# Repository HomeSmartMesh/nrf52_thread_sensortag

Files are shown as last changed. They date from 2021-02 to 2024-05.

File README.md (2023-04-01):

# nrf52_thread_sensortag
nRF52840 small sensor Tag, Low power design, battery operated

# documentation website
https://www.homesmartmesh.com/docs/microcontrollers/nrf52/thread_sensortag/
# community discussion
Free support, feedback and discussions right here on gihub
https://github.com/orgs/HomeSmartMesh/discussions

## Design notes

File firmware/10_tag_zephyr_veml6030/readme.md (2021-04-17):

# sensor tag hello

## environment variables
* `GNUARMEMB_TOOLCHAIN_PATH` = D:\tools\gnu_arm_embedded\9_2020-q2-update
* `ZEPHYR_BASE` = D:\Projects\zephyrproject\zephyr
* `ZEPHYR_TOOLCHAIN_VARIANT` = gnuarmemb

## usage
```bash
west build -b nrf52840_sensortag -- -DCONF_FILE=prj-shell.conf
west build -b nrf52840_sensortag -- -DCONF_FILE=prj-log.conf
west flash
```

error
```log
[00:00:00.325,012] <inf> main: Hello from Sensor Tag I2C example
[00:00:00.325,012] <inf> main: VEML6030 light sensor application

[00:00:00.325,042] <err> main: sensor: device not found.
```

https://docs.zephyrproject.org/latest/guides/porting/board_porting.html

https://stackoverflow.com/questions/62358554/zephyros-how-to-add-driver-module-to-out-of-tree-project

https://www.zephyrproject.org/how-to-build-drivers-for-zephyr-rtos/

https://interrupt.memfault.com/blog/building-drivers-on-zephyr

https://docs.zephyrproject.org/latest/reference/drivers/index.html
https://docs.zephyrproject.org/1.9.0/devices/drivers/drivers.html
https://docs.zephyrproject.org/latest/reference/peripherals/sensor.html

https://www.mouser.com/datasheet/2/427/veml6030-1767367.pdf
https://www.mouser.com/datasheet/2/418/5/NG_DS_MS8607-02BA01_B3-1134999.pdf

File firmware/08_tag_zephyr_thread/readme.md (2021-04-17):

# tag zephyr thread
## usage
```bash
west build -b nrf52840_sensortag -- -DCONF_FILE=prj-shell.conf
west build -b nrf52840_sensortag -- -DCONF_FILE=prj-log.conf
west flash
```
## sample documentation
https://www.homesmartmesh.com/docs/microcontrollers/nrf52/thread_sensortag/#08-tag-zephyr-thread

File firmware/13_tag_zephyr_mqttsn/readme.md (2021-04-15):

# option 1 nRF SDK
* nRF5_SDK_for_Thread_and_Zigbee_v4.1.0_32ce5f8\components\thread\mqtt_sn\mqtt_sn_client
* components\thread\mqtt_sn\mqtt_sn_client

# option 2 kyberpunk
* reference example
https://github.com/kyberpunk/openthread-mqttsn/blob/master/examples/c_mqttsn_publish_without_connect/main.c

* using a forked openthread with mqtt-sn support
https://github.com/kyberpunk/openthread

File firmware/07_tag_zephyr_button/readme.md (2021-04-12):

# sensor tag hello

## environment variables
* `GNUARMEMB_TOOLCHAIN_PATH` = D:\tools\gnu_arm_embedded\9_2020-q2-update
* `ZEPHYR_BASE` = D:\Projects\zephyrproject\zephyr
* `ZEPHYR_TOOLCHAIN_VARIANT` = gnuarmemb

## usage
```bash
west build -b nrf52840_sensortag
west flash
```

config
```bash
-- west build: generating a build system
Including boilerplate (Zephyr base): D:/Projects/zephyrproject/zephyr/cmake/app/boilerplate.cmake
-- Application: D:/Dev/nrf52/nrf52_thread_sensortag/firmware/07_tag_zephyr_button
-- Zephyr version: 2.5.99 (D:/Projects/zephyrproject/zephyr)
-- Found Python3: C:/Users/User/AppData/Local/Programs/Python/Python39/python.exe (found suitable exact version "3.9.0") found components: Interpreter
-- Found west (found suitable version "0.9.0", minimum required is "0.7.1")
-- Board: nrf52840_sensortag
-- Cache files will be written to: D:/Projects/zephyrproject/zephyr/.cache
-- Found toolchain: gnuarmemb (D:/tools/gnu_arm_embedded/9_2020-q2-update)
-- Found BOARD.dts: D:/Dev/nrf52/nrf52_thread_sensortag/firmware/boards/arm/nrf52840_sensortag/nrf52840_sensortag.dts
```

rtt log
```log
00> *** Booting Zephyr OS build zephyr-v2.5.0-159-g2bfaadffb807  ***
00> 
00> [00:00:00.334,259] <inf> main: Hello from Sensor Tag Button example
00> [00:00:00.334,289] <inf> main: Set up button at GPIO_1 pin 9
00> 
00> [00:00:01.334,350] <inf> main: loop: 0
00> [00:00:02.334,442] <inf> main: loop: 1
00> [00:00:03.334,533] <inf> main: loop: 2
00> [00:00:04.334,625] <inf> main: loop: 3
00> [00:00:05.334,716] <inf> main: loop: 4
00> [00:00:06.334,808] <inf> main: loop: 5
00> [00:00:07.334,899] <inf> main: loop: 6
00> [00:00:08.334,991] <inf> main: loop: 7
00> [00:00:09.335,083] <inf> main: loop: 8
00> [00:00:10.335,174] <inf> main: loop: 9
00> [00:00:11.335,266] <inf> main: loop: 10
00> [00:00:12.335,357] <inf> main: loop: 11
00> [00:00:13.335,449] <inf> main: loop: 12
00> [00:00:14.335,540] <inf> main: loop: 13
00> [00:00:15.335,632] <inf> main: loop: 14
00> [00:00:16.335,723] <inf> main: loop: 15
00> [00:00:17.335,815] <inf> main: loop: 16
00> [00:00:18.335,906] <inf> main: loop: 17
00> [00:00:19.335,998] <inf> main: loop: 18
00> [00:00:20.336,090] <inf> main: loop: 19
00> [00:00:21.336,181] <inf> main: loop: 20
00> [00:00:22.336,273] <inf> main: loop: 21
00> [00:00:23.336,364] <inf> main: loop: 22
00> [00:00:24.336,456] <inf> main: loop: 23
00> [00:00:25.336,547] <inf> main: loop: 24
00> [00:00:26.336,639] <inf> main: loop: 25
00> [00:00:27.336,730] <inf> main: loop: 26
00> [00:00:28.336,822] <inf> main: loop: 27
00> [00:00:29.336,914] <inf> main: loop: 28
00> [00:00:30.337,005] <inf> main: loop: 29
00> [00:00:31.337,097] <inf> main: loop: 30
00> [00:00:32.337,188] <inf> main: loop: 31
00> [00:00:32.920,257] <inf> main: Button pressed at 1078731
00> 
00> [00:00:33.282,348] <inf> main: Button pressed at 1090596
00> 
00> [00:00:33.337,249] <inf> main: loop: 32
00> [00:00:34.337,310] <inf> main: loop: 33
00> [00:00:35.337,402] <inf> main: loop: 34
00> [00:00:36.337,493] <inf> main: loop: 35
00> [00:00:37.337,585] <inf> main: loop: 36
00> [00:00:38.337,677] <inf> main: loop: 37
00> [00:00:39.337,768] <inf> main: loop: 38
00> [00:00:40.337,860] <inf> main: loop: 39
00> [00:00:41.337,951] <inf> main: loop: 40
00> [00:00:42.338,043] <inf> main: loop: 41
00> [00:00:43.338,134] <inf> main: loop: 42
00> [00:00:44.338,226] <inf> main: loop: 43
00> [00:00:45.338,317] <inf> main: loop: 44
00> *** Booting Zephyr OS build zephyr-v2.5.0-159-g2bfaadffb807  ***
00> 
00> [00:00:00.250,396] <inf> main: Hello from Sensor Tag Button example
00> [00:00:00.250,396] <inf> main: Set up button at GPIO_1 pin 9
00> 
00> [00:00:01.250,457] <inf> main: loop: 0
00> [00:00:02.250,549] <inf> main: loop: 1
00> [00:00:03.250,640] <inf> main: loop: 2
00> [00:00:04.250,732] <inf> main: loop: 3
00> [00:00:05.250,823] <inf> main: loop: 4
00> [00:00:05.709,991] <inf> main: Button pressed at 187105
00> 
00> [00:00:06.250,915] <inf> main: loop: 5
00> [00:00:07.250,976] <inf> main: loop: 6
00> [00:00:08.251,068] <inf> main: loop: 7
00> [00:00:09.251,159] <inf> main: loop: 8
00> [00:00:10.251,251] <inf> main: loop: 9
00> [00:00:11.251,342] <inf> main: loop: 10
00> [00:00:12.251,434] <inf> main: loop: 11
00> [00:00:13.251,525] <inf> main: loop: 12
00> [00:00:14.251,617] <inf> main: loop: 13
00> [00:00:15.251,708] <inf> main: loop: 14
00> [00:00:16.251,800] <inf> main: loop: 15
00> [00:00:17.251,892] <inf> main: loop: 16
00> [00:00:18.251,983] <inf> main: loop: 17
00> [00:00:19.252,075] <inf> main: loop: 18
00> [00:00:20.252,166] <inf> main: loop: 19
00> [00:00:21.252,258] <inf> main: loop: 20
00> [00:00:22.252,349] <inf> main: loop: 21
```

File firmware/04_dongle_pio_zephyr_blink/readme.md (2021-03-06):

* added `boards\nrf52840dongle_nrf52840.json`
* jlink is the default upload method for the nrf52840 boards
* sensor tag [documentation website](https://www.homesmartmesh.com/docs/microcontrollers/nrf52/thread_sensortag/)

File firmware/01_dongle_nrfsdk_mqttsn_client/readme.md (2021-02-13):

MQTT-SN Documentation https://www.homesmartmesh.com/docs/networks/thread/#mqtt-sn

This example is a portof the [nRFSDK for Thread and Zigbee v4.1.0](https://www.nordicsemi.com/Software-and-tools/Software/nRF5-SDK-for-Thread-and-Zigbee/Download#infotabs) [mqttsn_client_publisher example](examples\thread\mqttsn_client_publisher) to the nRF52840 USB dongle (PCA10059)

* Adapted Makefile
* As the usb dongle has only one user key KEY_0, the sequence of `search_gateway`, `connect`, `publish` is not cyclically executed when pressing KEY_0 multiple times.

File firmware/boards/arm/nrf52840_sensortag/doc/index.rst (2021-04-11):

.. _nrf52840_sensortag:

nRF52840 Sensor Tag
###################

Overview
********

The nRF52840 Sensor Tag is a small board including MS8607 and VEML6030 sensors, Nordic Semiconductor nRF52840 ARM Cortex-M4F CPU and the following devices:

* :abbr:`ADC (Analog to Digital Converter)`
* CLOCK
* FLASH
* :abbr:`GPIO (General Purpose Input Output)`
* :abbr:`I2C (Inter-Integrated Circuit)`
* :abbr:`MPU (Memory Protection Unit)`
* :abbr:`NVIC (Nested Vectored Interrupt Controller)`
* :abbr:`PWM (Pulse Width Modulation)`
* RADIO (Bluetooth Low Energy and 802.15.4)
* :abbr:`RTC (nRF RTC System Clock)`
* Segger RTT (RTT Console)
* :abbr:`UART (Universal asynchronous receiver-transmitter)`
* :abbr:`WDT (Watchdog Timer)`

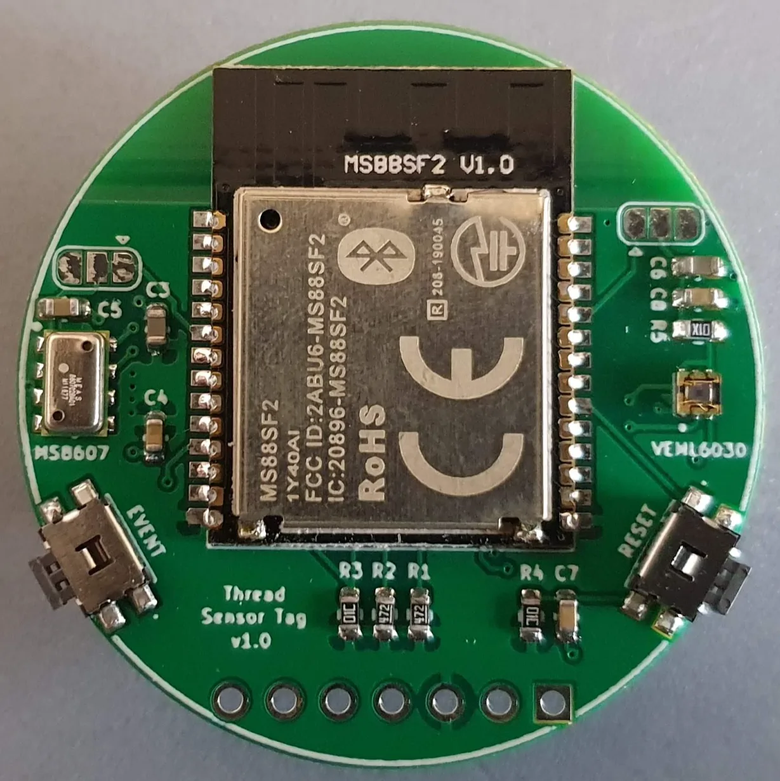
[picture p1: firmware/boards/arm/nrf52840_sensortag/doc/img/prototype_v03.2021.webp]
Thread Sensor Tag


     nRF52840 Thread Sensor Tag (Credit: Home Smart Mesh)

Hardware
********

nRF52840 DK has two external oscillators. The frequency of the slow clock
is 32.768 kHz. The frequency of the main clock is 32 MHz.

Supported Features
==================

The nrf52840_sensortag board configuration supports the following
hardware features:

+-----------+------------+----------------------+
| Interface | Controller | Driver/Component     |
+===========+============+======================+
| ADC       | on-chip    | adc                  |
+-----------+------------+----------------------+
| CLOCK     | on-chip    | clock_control        |
+-----------+------------+----------------------+
| FLASH     | on-chip    | flash                |
+-----------+------------+----------------------+
| GPIO      | on-chip    | gpio                 |
+-----------+------------+----------------------+
| I2C(M)    | on-chip    | i2c                  |
+-----------+------------+----------------------+
| MPU       | on-chip    | arch/arm             |
+-----------+------------+----------------------+
| NVIC      | on-chip    | arch/arm             |
+-----------+------------+----------------------+
| PWM       | on-chip    | pwm                  |
+-----------+------------+----------------------+
| RADIO     | on-chip    | Bluetooth,           |
|           |            | ieee802154           |
+-----------+------------+----------------------+
| RTC       | on-chip    | system clock         |
+-----------+------------+----------------------+
| RTT       | Segger     | console              |
+-----------+------------+----------------------+
| SPI(M/S)  | on-chip    | spi                  |
+-----------+------------+----------------------+
| UART      | on-chip    | serial               |
+-----------+------------+----------------------+
| WDT       | on-chip    | watchdog             |
+-----------+------------+----------------------+

Other hardware features are not supported by the Zephyr kernel.
See `nRF52840 DK website`_ and `Nordic Semiconductor Infocenter`_
for a complete list of nRF52840 Development Kit board hardware features.

Connections and IOs
===================

Push buttons
------------

* BUTTON1 = SW1 = P1.09

Programming and Debugging
*************************

Applications for the ``nrf52840_sensortag`` board configuration can be
built, flashed, and debugged in the usual way. See
:ref:`build_an_application` and :ref:`application_run` for more details on
building and running.

References
**********

.. target-notes::

.. _SensorTag website: https://www.homesmartmesh.com/docs/microcontrollers/nrf52/thread_sensortag/
.. _Nordic Semiconductor Infocenter: https://infocenter.nordicsemi.com
.. _J-Link Software and documentation pack: https://www.segger.com/jlink-software.html
.. _nRF52840 Product Specification: http://infocenter.nordicsemi.com/pdf/nRF52840_PS_v1.0.pdf

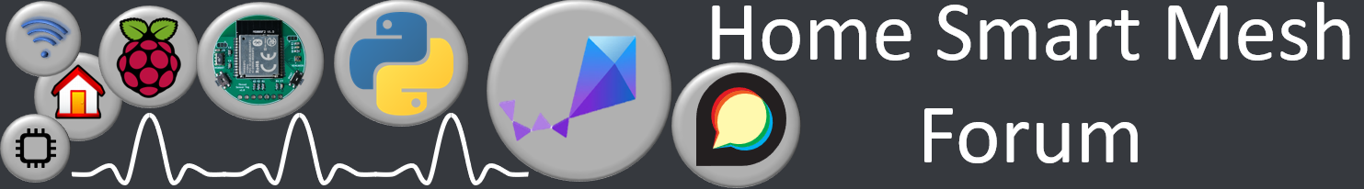
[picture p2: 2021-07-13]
media/forum.png

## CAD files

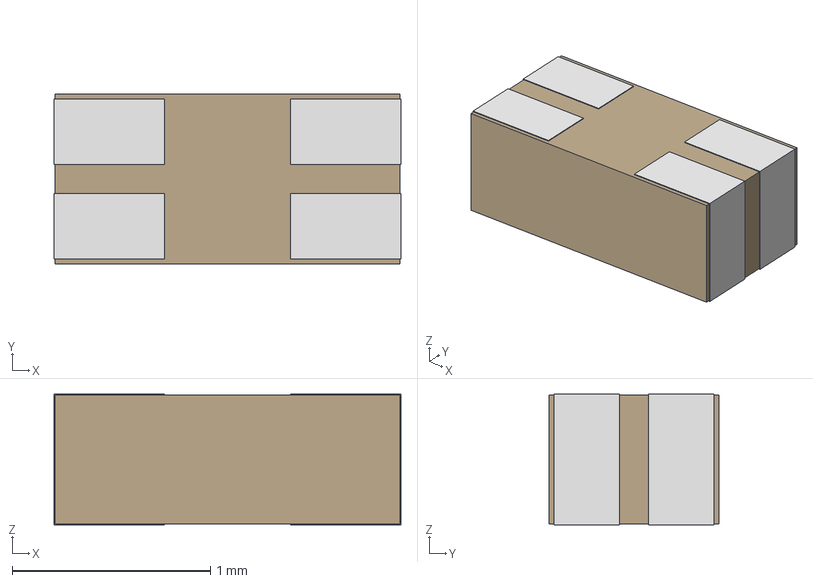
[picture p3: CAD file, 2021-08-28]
components/APHF1608LSEEQBDZGKC/3D/APHF1608SEEQBDZGKC_KNB.step
1.75 x 0.856 x 0.66 mm

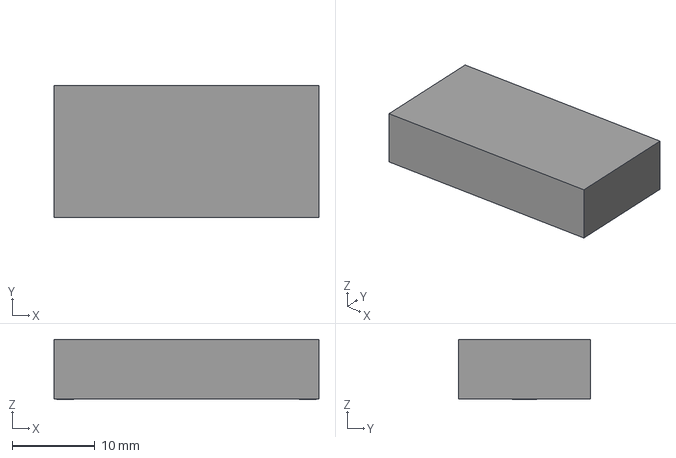
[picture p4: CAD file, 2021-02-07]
components/BA2032SM/3D/BA2032SM.stp
32.0 x 16.0 x 7.30 mm
Pins

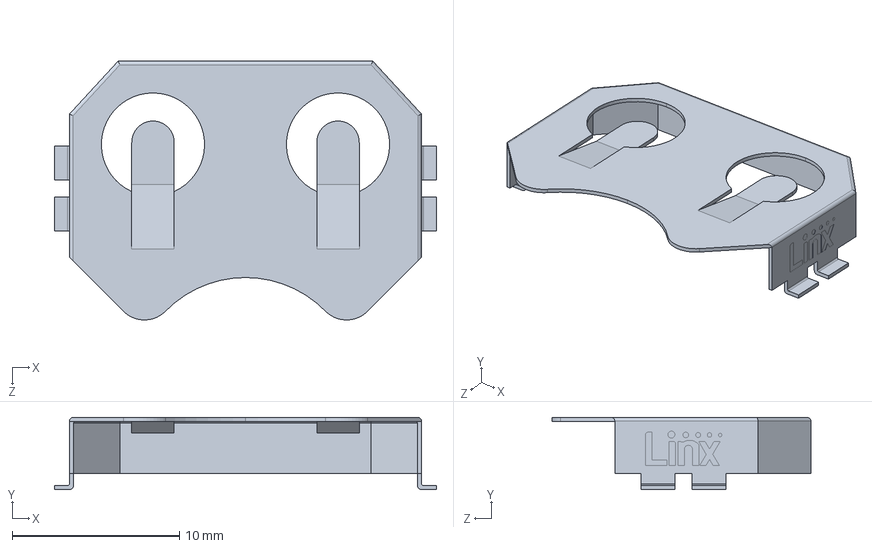
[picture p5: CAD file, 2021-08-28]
components/BAT-HLD-001/3D/BAT-HLD-001.stp
22.9 x 4.32 x 15.5 mm

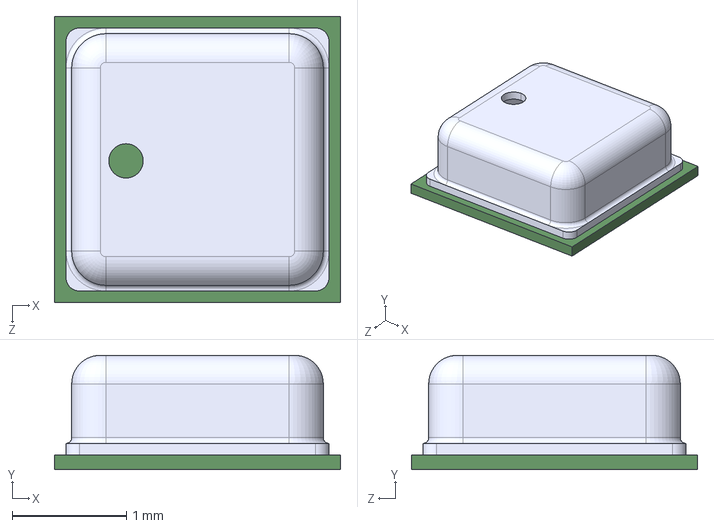
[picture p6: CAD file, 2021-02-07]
components/BME280/BME280.step
2.50 x 1.00 x 2.50 mm

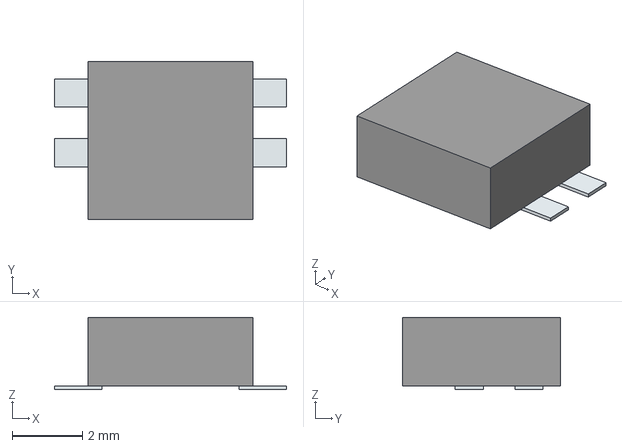
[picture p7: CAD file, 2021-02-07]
components/EVQ-PUA02K/3D/EVQ-PUA02K.stp
6.60 x 4.50 x 2.05 mm
Pins

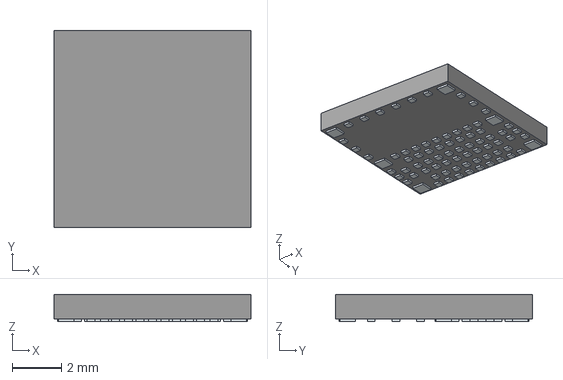
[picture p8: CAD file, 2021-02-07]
components/ISP1807-LR-RS/3D/ISP1807-LR-RS.stp
8.00 x 8.00 x 1.10 mm
Pins

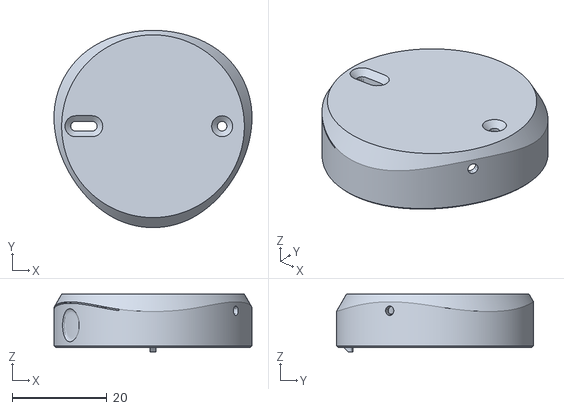
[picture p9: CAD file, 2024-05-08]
enclosure/trIoT_oberteil_PT2-1mm.stl
41.8 x 41.7 x 12.2

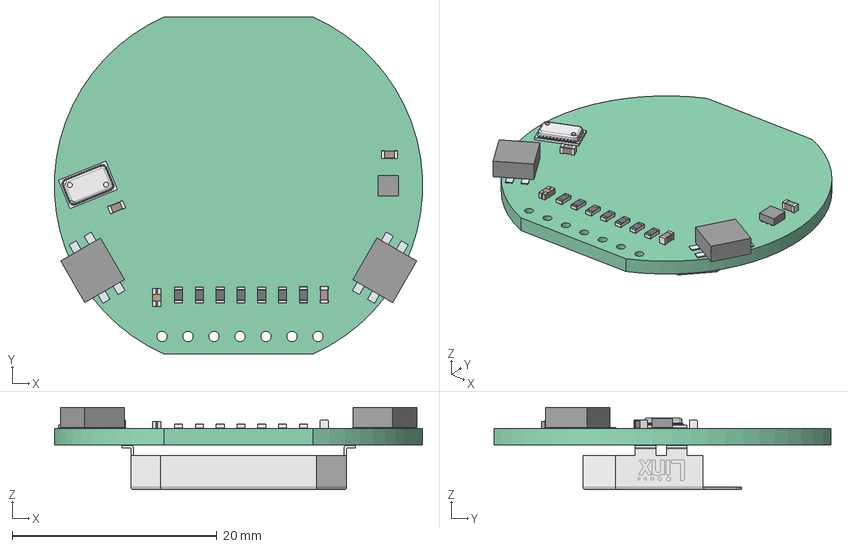
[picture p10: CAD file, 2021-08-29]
manufacturing/3D/3d-file.step
36.0 x 33.0 x 8.02 mm
PCB_Sketch
R7_R_0603_1608Metric_612A865A
R6_R_0603_1608Metric_612A8597
R5_R_0603_1608Metric_612A8537
LED1_APHF1608SEEQBDZGKC_KNB_612A85F8
IC3_C-MS860702BA01-50_602345E7
IC2_VEML6030_602345CD
C8_C_0603_1608Metric_602344F7
C5_C_0603_1608Metric_602344B5
R4_R_0603_1608Metric_612A862A
R3_R_0603_1608Metric_612A7F2F
R2_R_0603_1608Metric_612A8507
R1_R_0603_1608Metric_612A85C7
SW1_EVQ-PUA02K_601F8572
SW2_EVQ-PUA02K_601F8558
C7_C_0603_1608Metric_612A84D7
BT1_BAT-HLD-001_601FBF74

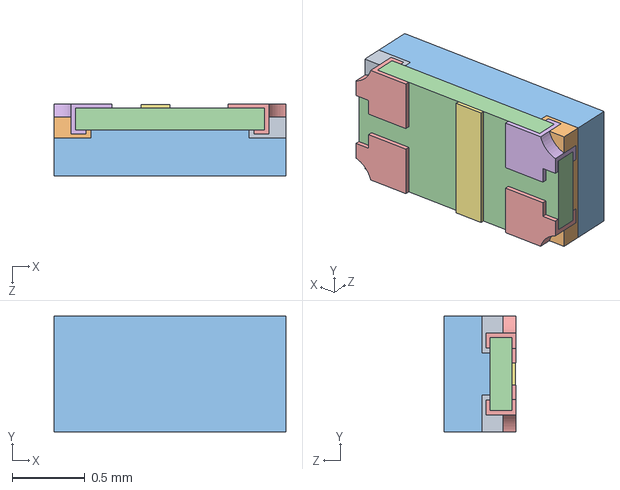
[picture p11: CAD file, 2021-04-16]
components/APHF1608LSEEQBDZGKC/3D/APHF1608_.STEP
1.60 x 0.8 x 0.5 mm

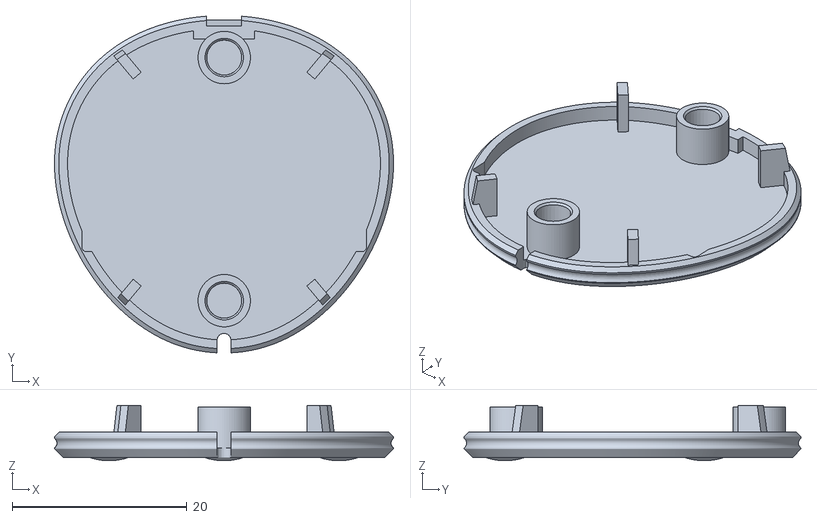
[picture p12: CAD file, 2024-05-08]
enclosure/trIoT_unterteil_PT2-1mm.stl
38.8 x 38.6 x 6.35

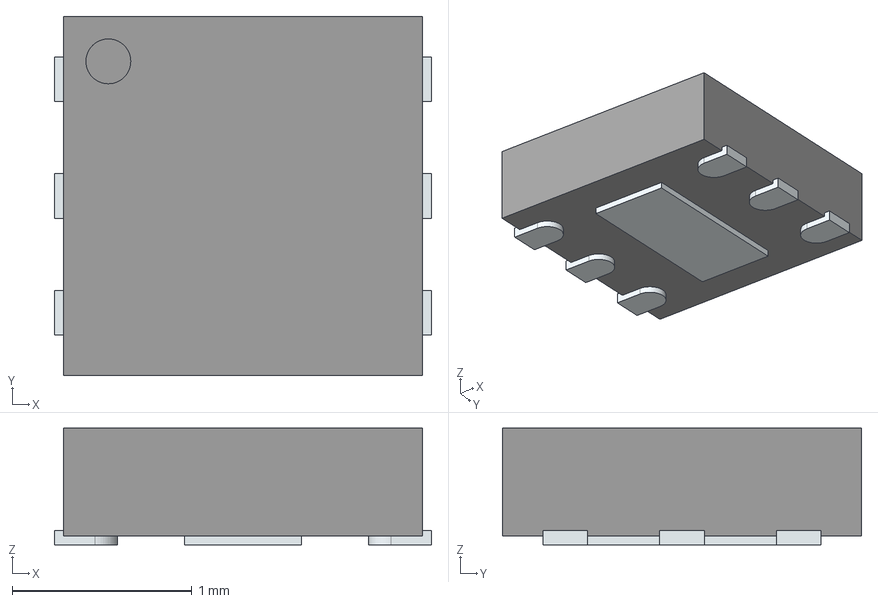
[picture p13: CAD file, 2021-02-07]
components/MAX44009EDT+T/3D/MAX44009EDT+T.stp
2.10 x 2.00 x 0.65 mm
ThermalPin
PinsArrayLR

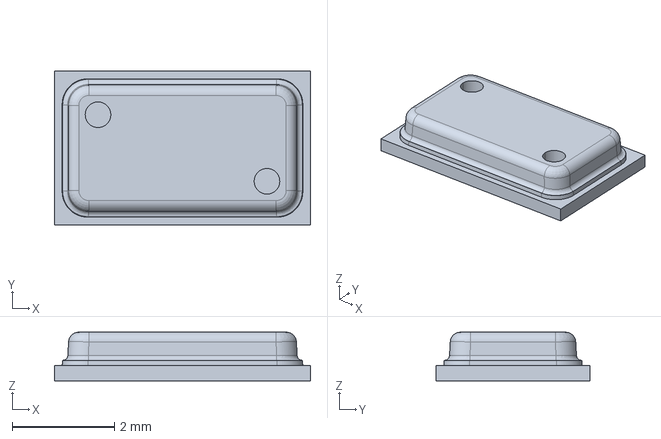
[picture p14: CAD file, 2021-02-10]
components/MS860702BA01-50/3D/MS860702BA01-50.stp
5.00 x 3.00 x 0.95 mm

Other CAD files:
components/APHF1608LSEEQBDZGKC/3D/APHF1608.IGS
components/BA2032SM/3D/BA2032SM.stl
components/EVQ-PUA02K/3D/EVQ-PUA02K.stl
components/ISP1807-LR-RS/3D/ISP1807-LR-RS.stl
components/MAX44009EDT+T/3D/MAX44009EDT+T.stl
components/VEML6030/3D/VEML6030.stl

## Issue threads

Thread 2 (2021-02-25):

Add LED to PCB

Informaticore, 2021-02-25:
We should add an LED to GPIO 2 (default GPIO for LEDs) which we can use for visual feedback

Informaticore, 2021-04-04:
Added RGB LED to the board
https://www.mouser.de/ProductDetail/Kingbright/APHF1608LSEEQBDZGKC?qs=YCa%2FAAYMW02iGkI4tWMQgA==

Connected to following GPIOs of the nRF chip:
- P0.04 - RED
- P0.06 - GREEN
- P0.08 - BLUE

Closed 2021-04-04.

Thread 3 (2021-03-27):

make firmware mqttsn_client_publisher failes

Informaticore, 2021-03-27:
to run make on mqttsn_client_publisher firmware example failes with:

```
Makefile:239: /components/toolchain/gcc/Makefile.common: No such file or directory
make: *** No rule to make target '/components/toolchain/gcc/Makefile.common'.  Stop.
```

Informaticore, 2021-03-27:
setting environment variable THREAD_SDK_ROOT to the thread SDK fixed the issue

wassfila, 2021-03-27:
right mentioned on the doc
https://www.homesmartmesh.com/docs/microcontrollers/nrf52/thread_sensortag/#firmware

Closed 2021-03-27.

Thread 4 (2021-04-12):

Sensor Tag improvements suggestions

wassfila, 2021-04-12:
I will target to add this sensor tag to the Zephyr project demo boards, for that to be accepted we have target a respectable quality for sw and hw.
For the PCB, after writing the .dts and looking at other boards, there are minor improvements that help follow other nordic boards conventions to make users feel familiar
Buttons

- [x] I suggest to rename the buttons similar to the USB dongle, the REET simply called "RESET" and not S1

- [x] the S2 then SW1 not S2

- if possible to make the words "RESET" and "SW1" visible from the top view, currently hidden under the switch

 - [x] The DEBUG / UART are way more helpful if they shift to top view, as I have to flip it every time to check
- to have shorter names CLK / DIO would be enough and "DEBUG" can be replaced with SWD

 - [x] I'm not sure if you really want to keep controlling the sensors with pios, does not seem to be necessary given the sleep modes of the sensors, it also makes it complex to align it with i2c drivers that are added in the dts, so not worth it. So unless you think controlling sensors with pio is really important, I would just simplify it.

- the space where the sensors solder pads were if remove would leave space for name and version on top, would also be more practical

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

Informaticore, 2021-04-12:
> if possible to make the words "RESET" and "SW1" visible from the top view, currently hidden under the switch
Do you wear glasses? Next to the buttons on the top-silk you can read: "RESET" for the reset button and "EVENT" for the SW1 Button. The name EVENT was kind of mire appealing to me then naming it SW1. :)
Or don't you have that on the Boards?

Informaticore, 2021-04-12:
> I'm not sure if you really want to keep controlling the sensors with pios, does not seem to be necessary given the sleep modes of the sensors, it also makes it complex to align it with i2c drivers that are added in the dts, so not worth it. So unless you think controlling sensors with pio is really important, I would just simplify it.

👍

wassfila, 2021-04-12:
I do have "RESET" and "EVENT", the dts usually starts counting from SW0, SW1,... while the dongle they started counting from 1, 2, I can't see any sw0.
The way the Thread sensor Tag now is opposed to the dongle and count from 1, maybe we can fix both issue in one by counting from 0

 - RESET = SW0 on schematics and on PCB only RESET visible
 - Event = SW1 on schematics and also SW1 can replace EVENT, the name is important as it should be matching the dts and is kind of a convention

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

wassfila, 2021-04-12:
Or another option is count from 1 and name them identical to the dongle also fine for me SW1 SW2 and visible RESET / SW1

Informaticore, 2021-04-12:
now I get it - you are talking about the designators! ok ok - yes, we can call them whatever we want, no opinions here. Usualy I would not even show them anyway

Informaticore, 2021-04-15:
Changes can be found https://github.com/HomeSmartMesh/nrf52_thread_sensortag/commit/817515b1eede50786a12f2edd8fc7260cec3bc14

Closed 2021-04-15.

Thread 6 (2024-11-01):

Sensor tags don't join thread network

hansinator, 2024-11-01:
Hi,

I set up an open thread border router according to your tutorial and started commissioning with the PSKd. Both of my sensor tags do not join the network. The firmware for the nordic usb stick linked in your post did not exist anymore so I used the current one and built it myself.

wassfila, 2024-11-01:
Only matters that firmware fits with open thread br software. I'd recommend to use both from recent versions.
I also recommend that you practice joining networks with cli before you try with custom firmware, it'll help you have a working reference to compare with, worst case, I'd recommend using a wireshark sniffer, it's hard, but helps you understand everything and find all problems.

wassfila, 2024-11-01:
And don't forget to fully delete the flash with factory reset, so that thread network config gets taken.

Informaticore, 2024-11-01:
I have seen such an issue before most likely a factory reset will help (I have documented it somewhere, but currently I can not find it somehow) @wassfila do you have it somewhere?

Informaticore, 2024-11-01:
@hansinator Which PSK did you used? I flashed the device with: ABCDE4

hansinator, 2024-11-01:
@wassfila I don't really get what you are talking about. I'm not using any custom firmware. I use the firmware from the openthread repository and followed this guide https://developer.nordicsemi.com/nRF_Connect_SDK/doc/v1.7-branch/matter/openthread_rcp_nrf_dongle.html to flash it. Can you elaborate on which flash I should delete?

I was mentioning it in case there is something different with the firmware that was referenced in the hackaday tutorial on how to set it up. All the links in the hackaday tutorial to the nrf dongle firmware and the guide are not working anymore.

Anyhow, since that's propbably just relaying the radio packets, I don't see why it should make any difference.

I am using ABCDE4 as the joiner key, but it does not work. I don't have any other thread devices yet to test it, but it looks like the reception is working. I receive packets that look like they come from the radio when I power up the sensor tag:

`Nov 01 18:08:59 piradio otbr-agent[703]: 03:09:43.869 [I] MeshForwarder-: Received IPv6 UDP msg, len:83, chksum:67b0, ecn:no, from:a21216a434ef9868, sec:no, prio:net, rss:-62.0
Nov 01 18:08:59 piradio otbr-agent[703]: 03:09:43.869 [I] MeshForwarder-:     src:[fe80:0:0:0:a012:16a4:34ef:9868]:19788
Nov 01 18:08:59 piradio otbr-agent[703]: 03:09:43.869 [I] MeshForwarder-:     dst:[ff02:0:0:0:0:0:0:1]:19788
`

I tried powering from a lab power supply to make sure there's enough juice, but it does not change anything.

Informaticore, 2024-11-01:
@hansinator here, check out this page at the very bottom: https://hackaday.io/page/22272-how-to-setup-a-open-thread-border-router-with-raspberry-pi-and-connect-the-thread-sensor-tag
Try to run the factory reset as it is described there.

> To do a factory reset you press the reset button and after the first hello signel (red,green,blue, and before the second helo signal) you press both button again for a quick boot. Once you see the hello signal press both buttons again. If you see the blue LED blinking 3 times, the device was factory reset.

Then you can try again to commission. If that does not help at all there might be an issue with the latest version of the RPC and the firmware of the Sensor Tag. But I don't think that this is the case dbh. I also was in the situation, that the comissioning worked but it did not connect for some reason. Thread is still relatively new and has some issues here and there and it is quite complex as well. We will figure it out.

hansinator, 2024-11-01:
The factory reset did the trick, thank you very much. It is strange though that both tags didn't work out-of-the-box.

Informaticore, 2024-11-01:
> The factory reset did the trick, thank you very much. It is strange though that both tags didn't work out-of-the-box.

it is indeed! there seems to be an issue with the initial comission. As I said, I have seen this multiple times already

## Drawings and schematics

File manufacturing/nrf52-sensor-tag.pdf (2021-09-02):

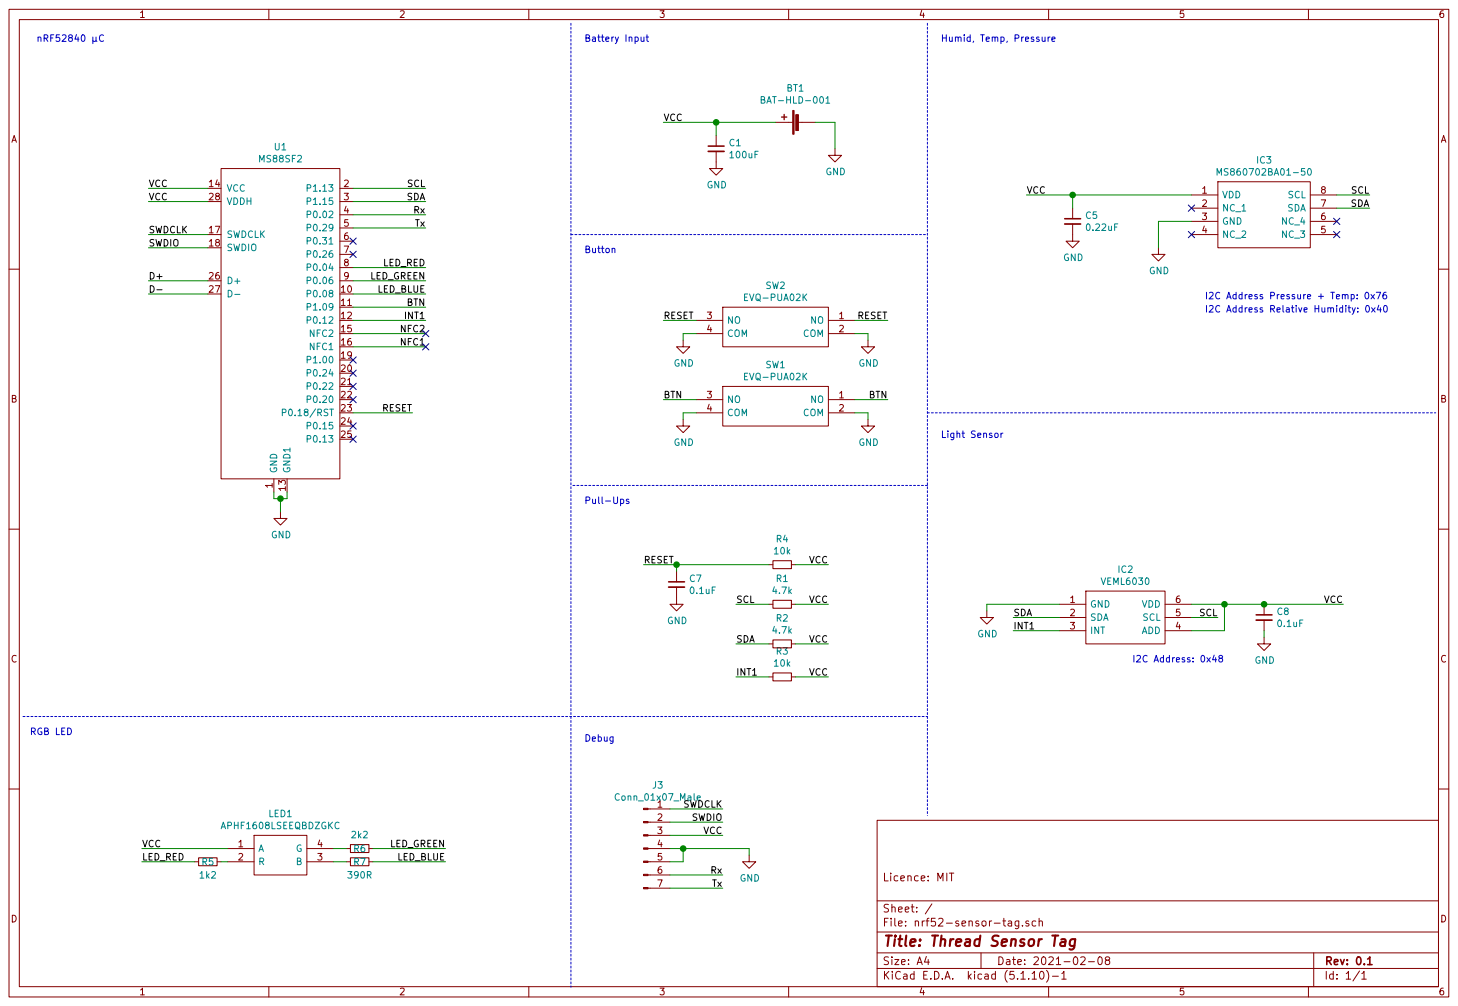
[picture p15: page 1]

1 P0.08 10 P1.09 11 P0.12 12 GND1 13 VCC 14 NFC2 15 NFC1 16 SWDCLK 17 SWDIO 18 P1.00 19 P1.13 2 P0.24 20 P0.22 21 P0.20 22 P0.18/RST 23 P0.15 24 P0.13 25 D+ 26 D- 27 VDDH 28 P1.15 3 P0.02 4 P0.29 5 P0.31 6 P0.26 7 P0.04 8 P0.06 9 U1 MS88SF2 GND GND GND GND

File: nrf52-sensor-tag.sch Sheet: / Licence: MIT

Id: 1/1 Title: Thread Sensor Tag

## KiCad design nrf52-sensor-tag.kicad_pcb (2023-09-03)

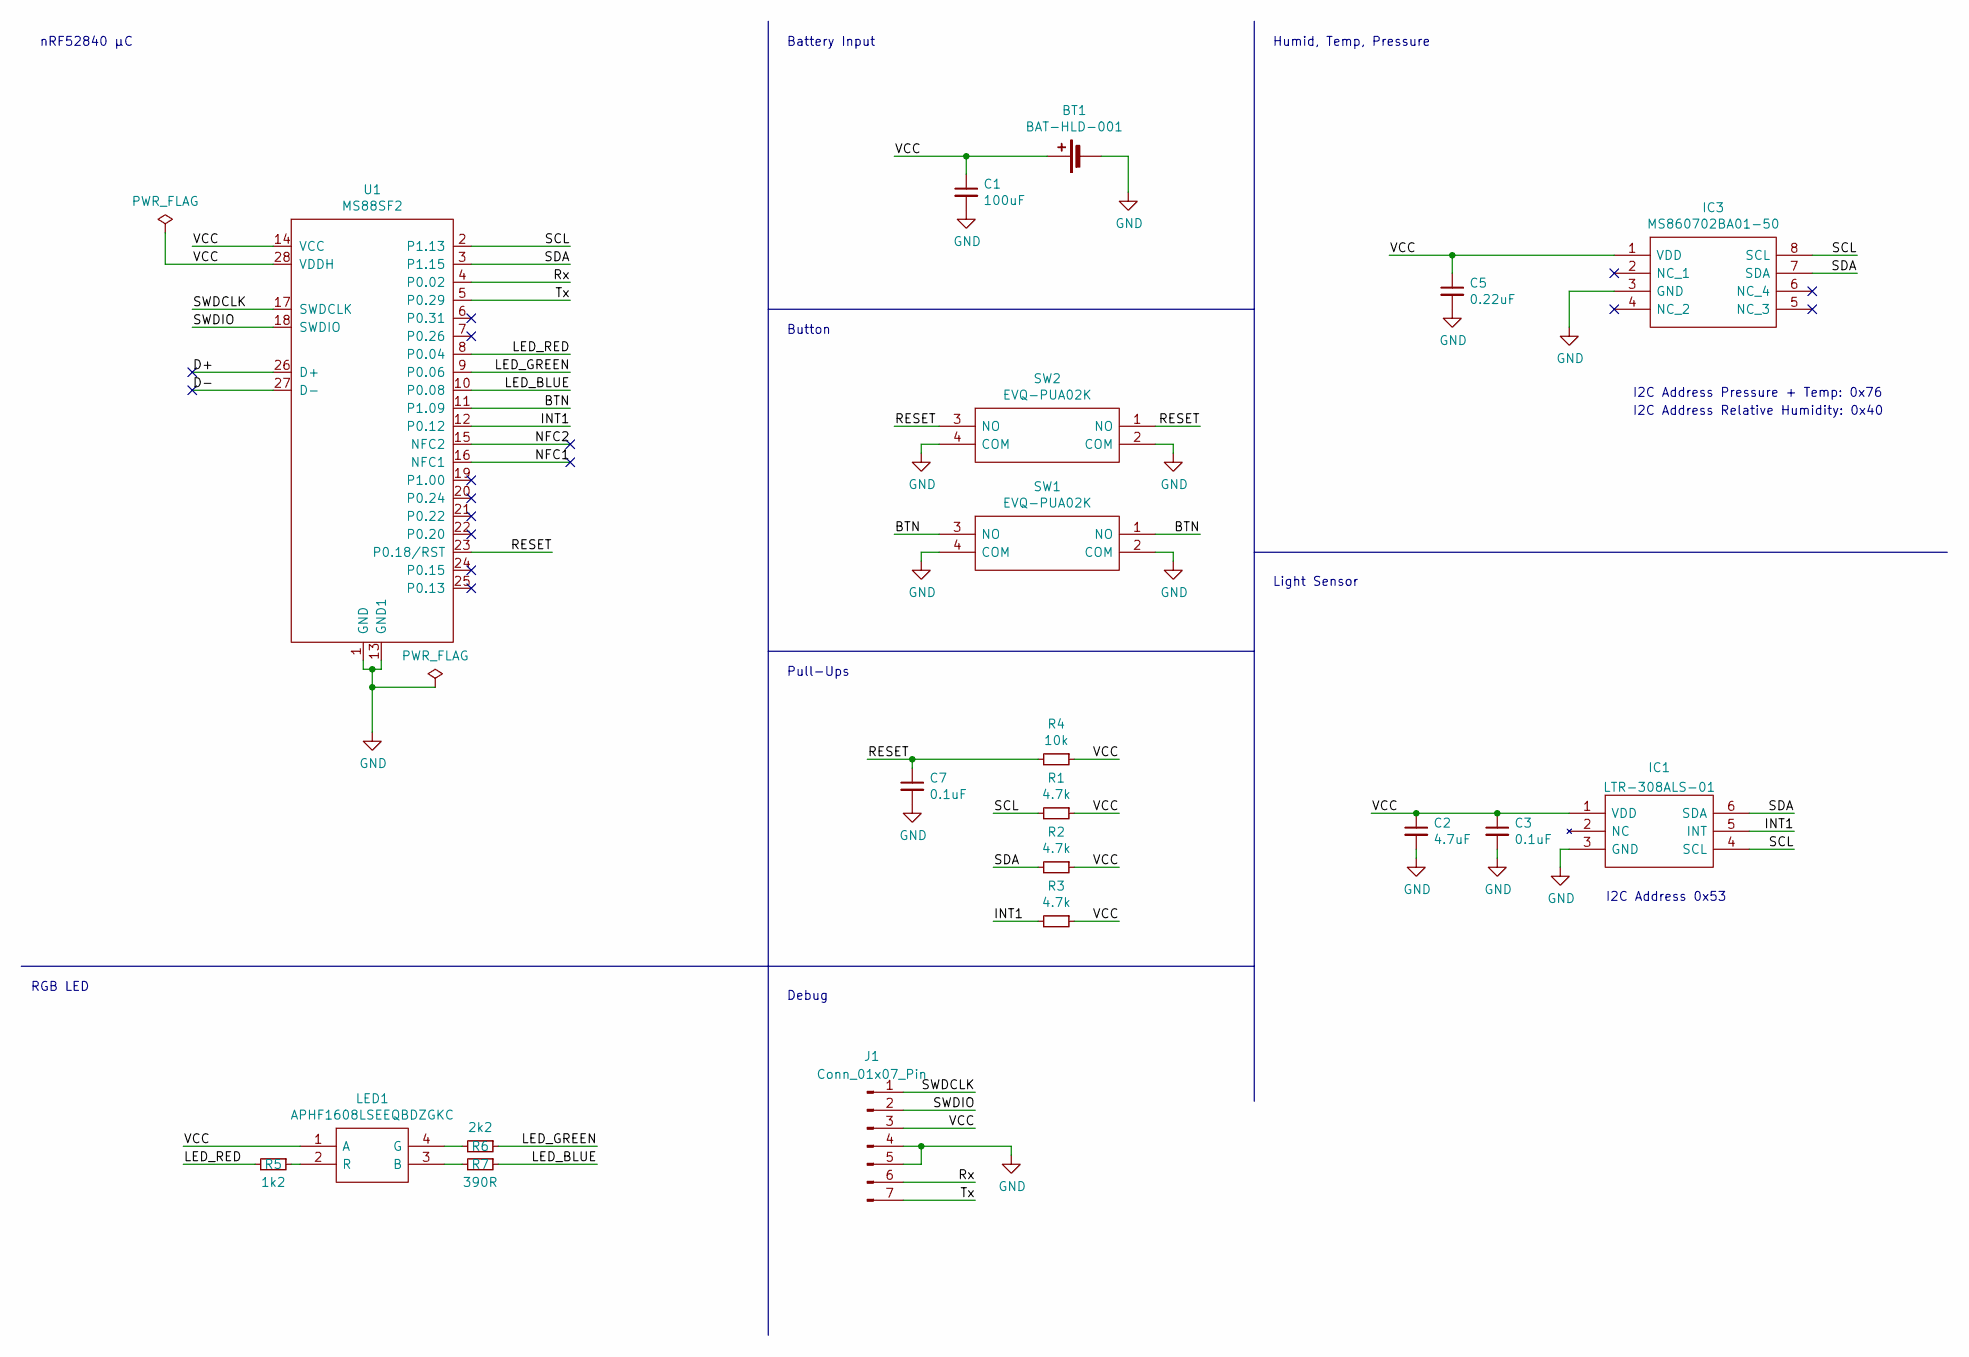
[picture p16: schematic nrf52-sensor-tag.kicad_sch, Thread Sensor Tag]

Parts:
BT1: BAT-HLD-001; BATHLD001
C1: 100uF; C_1210_3225Metric
C2: 4.7uF; C_0603_1608Metric
C3, C7: 0.1uF; C_0603_1608Metric
C5: 0.22uF; C_0603_1608Metric
IC1: LTR-308ALS-01; LTR303ALS01; Manufacturer_Part_Number LTR-308ALS-01; Mouser Part Number N/A
IC3: MS860702BA01-50; SON125P300X500X100-8N; Manufacturer_Part_Number MS860702BA01-50; Mouser Part Number 824-MS860702BA01-50
J1: Conn_01x07_Pin; PinSocket_1x07_P2.54mm_Vertical
LED1: APHF1608LSEEQBDZGKC; Manufacturer_Part_Number APHF1608LSEEQBDZGKC; Mouser Part Number 604-APHF1608LQBDZGKC
R1, R2, R3: 4.7k; R_0603_1608Metric
R4: 10k; R_0603_1608Metric
R5: 1k2; R_0603_1608Metric
R6: 2k2; R_0603_1608Metric
R7: 390R; R_0603_1608Metric
SW1, SW2: EVQ-PUA02K; EVQPUA02K; Manufacturer_Part_Number EVQ-PUA02K; Mouser Part Number 667-EVQ-PUA02K
U1: MS88SF2

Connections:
/BTN: SW1.1 (NO), SW1.3 (NO), U1.11 (P1.09)
/D+: U1.26 (D+)
/D-: U1.27 (D-)
/INT1: IC1.5 (INT), R3.2, U1.12 (P0.12)
/LED_BLUE: R7.1, U1.10 (P0.08)
/LED_GREEN: R6.1, U1.9 (P0.06)
/LED_RED: R5.2, U1.8 (P0.04)
/NFC1: U1.16 (NFC1)
/NFC2: U1.15 (NFC2)
/RESET: C7.1, R4.2, SW2.1 (NO), SW2.3 (NO), U1.23 (P0.18/RST)
/Rx: J1.6, U1.4 (P0.02)
/SCL: IC1.4 (SCL), IC3.8 (SCL), R1.2, U1.2 (P1.13)
/SDA: IC1.6 (SDA), IC3.7 (SDA), R2.2, U1.3 (P1.15)
/SWDCLK: J1.1, U1.17 (SWDCLK)
/SWDIO: J1.2, U1.18 (SWDIO)
/Tx: J1.7, U1.5 (P0.29)
/VCC: BT1.1 (+), C1.1, C2.1, C3.1, C5.1, IC1.1 (VDD), IC3.1 (VDD), J1.3, LED1.1 (A), R1.1, R2.1, R3.1, R4.1, U1.14 (VCC), U1.28 (VDDH)
GND: BT1.2 (-), C1.2, C2.2, C3.2, C5.2, C7.2, IC1.3 (GND), IC3.3 (GND), J1.4, J1.5, SW1.2 (COM), SW1.4 (COM), SW2.2 (COM), SW2.4 (COM), U1.1 (GND), U1.13 (GND1)
unnamed: LED1.3 (B), R7.2
unnamed: LED1.4 (G), R6.2
unnamed: LED1.2 (R), R5.1

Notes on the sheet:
Humid, Temp, Pressure
nRF52840 µC
Pull-Ups
RGB LED
Battery Input
I2C Address Pressure + Temp: 0x76
Button
I2C Address 0x53
Debug
I2C Address Relative Humidity: 0x40
Light Sensor

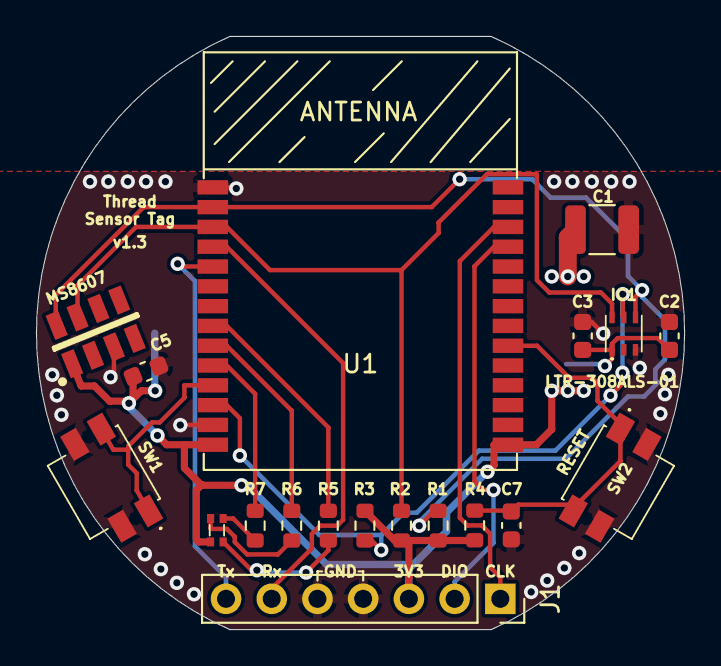
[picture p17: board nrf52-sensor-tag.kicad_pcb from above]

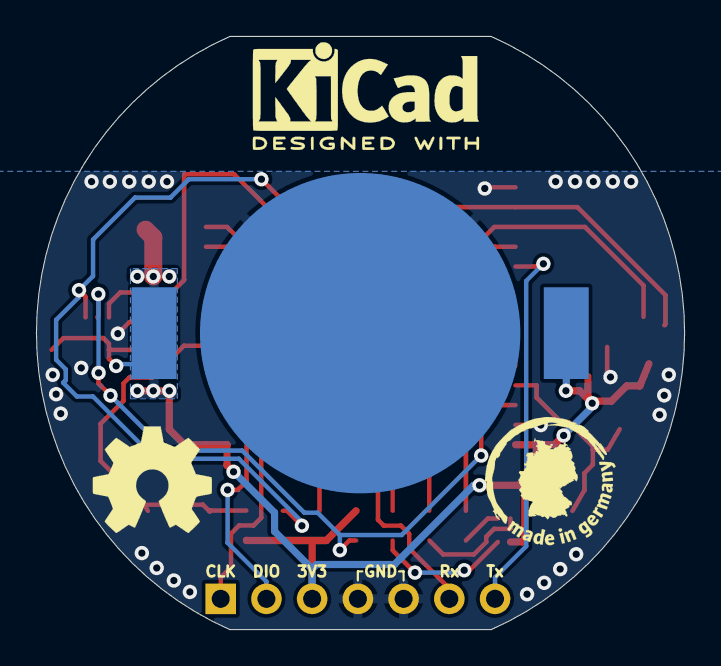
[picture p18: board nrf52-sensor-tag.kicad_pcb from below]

Board: 2 copper layers, 36.0 x 33.0 mm, 23 parts (4 on the bottom side), 17 nets.

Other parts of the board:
LOGO1: OSHW-Symbol_6.7x6mm_SilkScreen
LOGO2: LOGO; mig
LOGO3: KiCad-Logo2_5mm_SilkScreen

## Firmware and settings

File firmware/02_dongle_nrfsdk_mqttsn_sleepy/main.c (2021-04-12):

/**
 * Copyright (c) 2017 - 2020, Nordic Semiconductor ASA
 *
 * All rights reserved.
 *
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
 * 3. Neither the name of Nordic Semiconductor ASA nor the names of its
 *    contributors may be used to endorse or promote products derived from this
 *    software without specific prior written permission.
 *
 * 4. This software, with or without modification, must only be used with a
 *    Nordic Semiconductor ASA integrated circuit.
 *
 * 5. Any software provided in binary form under this license must not be reverse
 *    engineered, decompiled, modified and/or disassembled.
 *
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
 */
/** @file
 *
 * @defgroup thread_mqttsn_sleepy_publisher_example_main main.c
 * @{
 * @ingroup thread_mqttsn_sleepy_publisher_example
 * @brief Thread MQTT-SN Sleepy Publisher Example Application main file.
 *
 * @details This example demonstrates an MQTT-SN sleepy publisher application that enables to toggle
 *          BSP_LED_2 on a board with related MQTT-SN sleepy subscriber application via MQTT-SN messages.
 *          As the MQTT-SN sleepy publisher has no subscriptions, it will not need to receive data except
 *          for ACKs for its own messages, so asynchronous receiving is not needed. It therefore serves
 *          as a Thread Sleepy End Device.
 */

#include <stdbool.h>
#include <stdint.h>
#include <string.h>

#include "app_timer.h"
#include "bsp_thread.h"
#include "nrf_assert.h"
#include "nrf_log.h"
#include "nrf_log_ctrl.h"
#include "nrf_log_default_backends.h"

#include "mqttsn_client.h"
#include "thread_utils.h"

#include <openthread/ip6.h>
#include <openthread/thread.h>

#define DEFAULT_CHILD_TIMEOUT    40                                         /**< Thread child timeout [s]. */
#define DEFAULT_POLL_PERIOD      1000                                       /**< Thread Sleepy End Device polling period when MQTT-SN Asleep. [ms] */
#define SHORT_POLL_PERIOD        100                                        /**< Thread Sleepy End Device polling period when MQTT-SN Awake. [ms] */
#define SEARCH_GATEWAY_TIMEOUT   20                                          /**< MQTT-SN Gateway discovery procedure timeout in [s]. */                                   

static mqttsn_client_t      m_client;                                       /**< An MQTT-SN client instance. */
static mqttsn_remote_t      m_gateway_addr;                                 /**< A gateway address. */
static uint8_t              m_gateway_id;                                   /**< A gateway ID. */
static mqttsn_connect_opt_t m_connect_opt;                                  /**< Connect options for the MQTT-SN client. */
static uint8_t              m_led_state        = 0;                         /**< Previously sent BSP_LED_2 command. */
static uint16_t             m_msg_id           = 0;                         /**< Message ID thrown with MQTTSN_EVENT_TIMEOUT. */
static char                 m_client_id[]      = "nRF52840_publisher";      /**< The MQTT-SN Client's ID. */
static char                 m_topic_name[]     = "nRF52840_resources/led3"; /**< Name of the topic corresponding to subscriber's BSP_LED_2. */
static mqttsn_topic_t       m_topic            =                            /**< Topic corresponding to subscriber's BSP_LED_2. */
{
    .p_topic_name = (unsigned char *)m_topic_name,
    .topic_id     = 0,
};

/***************************************************************************************************
 * @section MQTT-SN
 **************************************************************************************************/

/**@brief Turns the MQTT-SN network indication LED on.
 *
 * @details This LED is on when an MQTT-SN client is in connected or awake state.
 */
static void light_on(void)
{
    LEDS_ON(BSP_LED_3_MASK);
}

/**@brief Turns the MQTT-SN network indication LED off.
 *
 * @details This LED is on when an MQTT-SN client is in disconnected or asleep state.
 */
static void light_off(void)
{
    LEDS_OFF(BSP_LED_3_MASK);
}

/**@brief Puts MQTT-SN client in sleep mode.
 *
 * @details This function changes Thread Sleepy End Device polling period to default.
 */
static void sleep(void)
{
    otError error;
    
    error = otLinkSetPollPeriod(thread_ot_instance_get(), DEFAULT_POLL_PERIOD);
    ASSERT(error == OT_ERROR_NONE);
}

/**@brief Puts MQTT-SN client in active mode.
 *
 * @details This function changes Thread Sleepy End Device polling period to short.
 */
static void wake_up(void)
{
    otError error;

    error = otLinkSetPollPeriod(thread_ot_instance_get(), SHORT_POLL_PERIOD);
    ASSERT(error == OT_ERROR_NONE);
}

/**@brief Initializes MQTT-SN client's connection options.
 */
static void connect_opt_init(void)
{
    m_connect_opt.alive_duration = MQTTSN_DEFAULT_ALIVE_DURATION,
    m_connect_opt.clean_session  = MQTTSN_DEFAULT_CLEAN_SESSION_FLAG,
    m_connect_opt.will_flag      = MQTTSN_DEFAULT_WILL_FLAG,
    m_connect_opt.client_id_len  = strlen(m_client_id),

    memcpy(m_connect_opt.p_client_id, (unsigned char *)m_client_id, m_connect_opt.client_id_len);
}

/**@brief Processes GWINFO message from a gateway.
 *
 * @details This function initializes MQTT-SN Client's connect options and launches the connect procedure.
 *
 * @param[in]    p_event  Pointer to MQTT-SN event.
 */
static void gateway_info_callback(mqttsn_event_t * p_event)
{
    m_gateway_addr  = *(p_event->event_data.connected.p_gateway_addr);
    m_gateway_id    = p_event->event_data.connected.gateway_id;
}

/**@brief Processes CONNACK message from a gateway.
 *
 * @details This function launches the topic registration procedure if necessary.
 */
static void connected_callback(void)
{
    light_on();

    uint32_t err_code = mqttsn_client_topic_register(&m_client,
                                                     m_topic.p_topic_name,
                                                     strlen(m_topic_name),
                                                     &m_msg_id);
    if (err_code != NRF_SUCCESS)
    {
        NRF_LOG_ERROR("REGISTER message could not be sent. Error code: 0x%x\r\n", err_code);
    }
}

/**@brief Processes DISCONNECT message from a gateway. */
static void disconnected_callback(void)
{
    light_off();
    sleep();
}

/**@brief Processes REGACK message from a gateway.
 *
 * @details This function puts the client in sleep mode.
 *
 * @param[in] p_event Pointer to MQTT-SN event.
 */
static void regack_callback(mqttsn_event_t * p_event)
{
    m_topic.topic_id = p_event->event_data.registered.packet.topic.topic_id;
    NRF_LOG_INFO("MQTT-SN event: Topic has been registered with ID: %d.\r\n",
                 p_event->event_data.registered.packet.topic.topic_id);

    sleep();
}

/**@brief Processes PUBACK message from a gateway.
 *
 * @details This function puts the client in sleep mode.
 */
static void puback_callback(void)
{
    sleep();
}

/**@brief Processes DISCONNECT message being a response to sleep request.
 *
 * @details This function puts the client in sleep mode.
 */
static void sleep_callback(void)
{
    sleep();
}

/**@brief Processes callback from keep-alive timer timeout.
 *
 * @details This function puts the client in active mode.
 */
static void wakeup_callback(void)
{
    wake_up();
}

/**@brief Processes retransmission limit reached event. */
static void timeout_callback(mqttsn_event_t * p_event)
{
    NRF_LOG_INFO("MQTT-SN event: Timed-out message: %d. Message ID: %d.\r\n",
                  p_event->event_data.error.msg_type,
                  p_event->event_data.error.msg_id);
}

/**@brief Processes results of gateway discovery procedure. */
static void searchgw_timeout_callback(mqttsn_event_t * p_event)
{
    NRF_LOG_INFO("MQTT-SN event: Gateway discovery result: 0x%x.\r\n", p_event->event_data.discovery);
    sleep();
}

/**@brief Function for handling MQTT-SN events. */
void mqttsn_evt_handler(mqttsn_client_t * p_client, mqttsn_event_t * p_event)
{
    switch (p_event->event_id)
    {
        case MQTTSN_EVENT_GATEWAY_FOUND:
            NRF_LOG_INFO("MQTT-SN event: Client has found an active gateway.\r\n");
            gateway_info_callback(p_event);
            break;

        case MQTTSN_EVENT_CONNECTED:
            NRF_LOG_INFO("MQTT-SN event: Client connected.\r\n");
            connected_callback();
            break;

        case MQTTSN_EVENT_DISCONNECTED:
            NRF_LOG_INFO("MQTT-SN event: Client disconnected.\r\n");
            disconnected_callback();
            break;

        case MQTTSN_EVENT_REGISTERED:
            NRF_LOG_INFO("MQTT-SN event: Client registered topic.\r\n");
            regack_callback(p_event);
            break;

        case MQTTSN_EVENT_PUBLISHED:
            NRF_LOG_INFO("MQTT-SN event: Client has successfully published content.\r\n");
            puback_callback();
            break;

        case MQTTSN_EVENT_SLEEP_PERMIT:
            NRF_LOG_INFO("MQTT-SN event: Client permitted to sleep.\r\n");
            sleep_callback();
            break;

        case MQTTSN_EVENT_SLEEP_STOP:
            NRF_LOG_INFO("MQTT-SN event: Client wakes up.\r\n");
            wakeup_callback();
            break;

        case MQTTSN_EVENT_TIMEOUT:
            NRF_LOG_INFO("MQTT-SN event: Retransmission retries limit has been reached.\r\n");
            timeout_callback(p_event);
            break;

        case MQTTSN_EVENT_SEARCHGW_TIMEOUT:
            NRF_LOG_INFO("MQTT-SN event: Gateway discovery procedure has finished.\r\n");
            searchgw_timeout_callback(p_event);
            break;

        default:
            break;
    }
}

/***************************************************************************************************
 * @section State
 **************************************************************************************************/

static void state_changed_callback(uint32_t flags, void * p_context)
{
    NRF_LOG_INFO("State changed! Flags: 0x%08x Current role: %d\r\n",
                 flags, otThreadGetDeviceRole(p_context));
}

/***************************************************************************************************
 * @section Buttons
 **************************************************************************************************/

static void led_state_pub(uint8_t led_state)
{
    uint32_t err_code = mqttsn_client_publish(&m_client, m_topic.topic_id, &led_state, 1, &m_msg_id);
    if (err_code != NRF_SUCCESS)
    {
        NRF_LOG_ERROR("PUBLISH message could not be sent. Error code: 0x%x\r\n", err_code)
    }
}

static void publish(void)
{
    m_led_state = m_led_state == 1 ? 0 : 1;
    led_state_pub(m_led_state);
}

static void bsp_event_handler(bsp_event_t event)
{
    static uint8_t sequence = 0;
    if (otThreadGetDeviceRole(thread_ot_instance_get()) < OT_DEVICE_ROLE_CHILD )
    {
        (void)event;
        return;
    }

    switch (event)
    {
        case BSP_EVENT_KEY_0:
        {
            if(sequence == 0){
                NRF_LOG_INFO("(0)");
                wake_up();
                uint32_t err_code = mqttsn_client_search_gateway(&m_client, SEARCH_GATEWAY_TIMEOUT);
                if (err_code != NRF_SUCCESS)
                {
                    NRF_LOG_ERROR("SEARCH GATEWAY message could not be sent. Error: 0x%x\r\n", err_code);
                }
                sequence = 1;
            }else if(sequence == 1){
                NRF_LOG_INFO("(1)");
                wake_up();
                NRF_LOG_INFO("Wake up first time");
                uint32_t err_code;
                err_code = mqttsn_client_connect(&m_client, &m_gateway_addr, m_gateway_id, &m_connect_opt);
                if (err_code != NRF_SUCCESS)
                {
                    NRF_LOG_ERROR("CONNECT message could not be sent. Error: 0x%x\r\n", err_code);
                }
                sequence = 2;
            }
            else if(sequence == 2){
                NRF_LOG_INFO("(2)");
                NRF_LOG_INFO("Wake up next times");
                wake_up();
                publish();
                sequence = 0;
            }
            break;
        }
        case BSP_EVENT_KEY_1:
        {
            wake_up();
            uint32_t err_code = mqttsn_client_search_gateway(&m_client, SEARCH_GATEWAY_TIMEOUT);
            if (err_code != NRF_SUCCESS)
            {
                NRF_LOG_ERROR("SEARCH GATEWAY message could not be sent. Error: 0x%x\r\n", err_code);
            }
            break;
        }

        case BSP_EVENT_KEY_2:
        {
            wake_up();

            uint32_t err_code;

            if (mqttsn_client_state_get(&m_client) == MQTTSN_CLIENT_CONNECTED)
            {
                err_code = mqttsn_client_disconnect(&m_client);
                if (err_code != NRF_SUCCESS)
                {
                    NRF_LOG_ERROR("DISCONNECT message could not be sent. Error: 0x%x\r\n", err_code);
                }
            }
            else
            {
                err_code = mqttsn_client_connect(&m_client, &m_gateway_addr, m_gateway_id, &m_connect_opt);
                if (err_code != NRF_SUCCESS)
                {
                    NRF_LOG_ERROR("CONNECT message could not be sent. Error: 0x%x\r\n", err_code);
                }
            }
            break;
        }

        case BSP_EVENT_KEY_3:
        {
            wake_up();
            publish();
            break;
        }

        default:
        {
            break;
        }
    }
}

/***************************************************************************************************
 * @section Initialization
 **************************************************************************************************/

/**@brief Function for initializing the Application Timer Module.
 */
static void timer_init(void)
{
    uint32_t err_code = app_timer_init();
    APP_ERROR_CHECK(err_code);
}

/**@brief Function for initializing the LEDs.
 */
static void leds_init(void)
{
    LEDS_CONFIGURE(LEDS_MASK);
    LEDS_OFF(LEDS_MASK);
}

/**@brief Function for initializing the nrf log module.
 */
static void log_init(void)
{
    ret_code_t err_code = NRF_LOG_INIT(NULL);
    APP_ERROR_CHECK(err_code);

    NRF_LOG_DEFAULT_BACKENDS_INIT();
}

/**@brief Function for initializing the Thread Board Support Package.
 */
static void thread_bsp_init(void)
{
    uint32_t err_code;
    err_code = bsp_init(BSP_INIT_LEDS | BSP_INIT_BUTTONS, bsp_event_handler);
    APP_ERROR_CHECK(err_code);

    err_code = bsp_thread_init(thread_ot_instance_get());
    APP_ERROR_CHECK(err_code);
}

/**@brief Function for initializing the Thread Stack.
 */
static void thread_instance_init(void)
{
    thread_configuration_t thread_configuration =
    {
        .radio_mode            = THREAD_RADIO_MODE_RX_ON_WHEN_IDLE,
        .autocommissioning     = true,
        .poll_period           = DEFAULT_POLL_PERIOD,
        .default_child_timeout = DEFAULT_CHILD_TIMEOUT,
    };

    thread_init(&thread_configuration);
    thread_state_changed_callback_set(state_changed_callback);
}

/**@brief Function for initializing the MQTTSN client.
 */
static void mqttsn_init(void)
{
    uint32_t err_code = mqttsn_client_init(&m_client,
                                           MQTTSN_DEFAULT_CLIENT_PORT,
                                           mqttsn_evt_handler,
                                           thread_ot_instance_get());
    APP_ERROR_CHECK(err_code);

    connect_opt_init();
}

/***************************************************************************************************
 * @section Main
 **************************************************************************************************/

int main(int argc, char *argv[])
{
    log_init();
    timer_init();
    leds_init();

    thread_instance_init();
    thread_bsp_init();
    mqttsn_init();

    while (true)
    {
        thread_process();

        if (NRF_LOG_PROCESS() == false)
        {
            thread_sleep();
        }
    }
}

/**
 *@}
 **/

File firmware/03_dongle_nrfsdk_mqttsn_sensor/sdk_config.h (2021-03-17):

/**
 * Copyright (c) 2017 - 2020, Nordic Semiconductor ASA
 *
 * All rights reserved.
 *
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
 * 3. Neither the name of Nordic Semiconductor ASA nor the names of its
 *    contributors may be used to endorse or promote products derived from this
 *    software without specific prior written permission.
 *
 * 4. This software, with or without modification, must only be used with a
 *    Nordic Semiconductor ASA integrated circuit.
 *
 * 5. Any software provided in binary form under this license must not be reverse
 *    engineered, decompiled, modified and/or disassembled.
 *
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
 */



#ifndef SDK_CONFIG_H
#define SDK_CONFIG_H
// <<< Use Configuration Wizard in Context Menu >>>\n
#ifdef USE_APP_CONFIG
#include "app_config.h"
#endif
// <h> OpenThread 

//==========================================================
// <h> openthread - OpenThread stack

//==========================================================
// <o> THREAD_PANID - 802.15.4 PAN ID used by Thread  <0-65535> 


// <i> 802.15.4 PAN ID used by Thread. Defaults to 0xABCD.

#ifndef THREAD_PANID
#define THREAD_PANID 4660
#endif

// <o> THREAD_CHANNEL - 802.15.4 channel used by Thread  <11-26> 


// <i> 802.15.4 channel used by Thread. Defaults to 11.

#ifndef THREAD_CHANNEL
#define THREAD_CHANNEL 13
#endif

// </h> 
//==========================================================

// </h> 
//==========================================================


// <h> Application
// <o> TWI_DEFAULT_CONFIG_FREQUENCY  - Frequency
 
// <26738688=> 100k 
// <67108864=> 250k 
// <104857600=> 400k 

#ifndef TWI_DEFAULT_CONFIG_FREQUENCY
#define TWI_DEFAULT_CONFIG_FREQUENCY 26738688
#endif

// </h> 
//==========================================================


// <h> nRF_Drivers 

// <e> TWI_ENABLED - nrf_drv_twi - TWI/TWIM peripheral driver - legacy layer
    //==========================================================
    #ifndef TWI_ENABLED
    #define TWI_ENABLED 1
    #endif

    // <q> TWI_DEFAULT_CONFIG_CLR_BUS_INIT  - Enables bus clearing procedure during init
    

    #ifndef TWI_DEFAULT_CONFIG_CLR_BUS_INIT
    #define TWI_DEFAULT_CONFIG_CLR_BUS_INIT 0
    #endif

    // <q> TWI_DEFAULT_CONFIG_HOLD_BUS_UNINIT  - Enables bus holding after uninit
    

    #ifndef TWI_DEFAULT_CONFIG_HOLD_BUS_UNINIT
    #define TWI_DEFAULT_CONFIG_HOLD_BUS_UNINIT 0
    #endif

    // <o> TWI_DEFAULT_CONFIG_IRQ_PRIORITY  - Interrupt priority
    

    // <i> Priorities 0,2 (nRF51) and 0,1,4,5 (nRF52) are reserved for SoftDevice
    // <0=> 0 (highest) 
    // <1=> 1 
    // <2=> 2 
    // <3=> 3 
    // <4=> 4 
    // <5=> 5 
    // <6=> 6 
    // <7=> 7 

    #ifndef TWI_DEFAULT_CONFIG_IRQ_PRIORITY
    #define TWI_DEFAULT_CONFIG_IRQ_PRIORITY 7
    #endif

    // <e> TWI0_ENABLED - Enable TWI0 instance
        //==========================================================
        #ifndef TWI0_ENABLED
        #define TWI0_ENABLED 1
        #endif
        // <q> TWI0_USE_EASY_DMA  - Use EasyDMA (if present)
        

        #ifndef TWI0_USE_EASY_DMA
        #define TWI0_USE_EASY_DMA 1
        #endif

    // </e>

    // <e> TWI1_ENABLED - Enable TWI1 instance
        //==========================================================
        #ifndef TWI1_ENABLED
        #define TWI1_ENABLED 0
        #endif
        // <q> TWI1_USE_EASY_DMA  - Use EasyDMA (if present)
        

        #ifndef TWI1_USE_EASY_DMA
        #define TWI1_USE_EASY_DMA 1
        #endif

    // </e>

// </e>

//=========================== TWI dependency ===============================

#if TWI0_ENABLED
#define TWI_INSTANCE_ID     0
#elif TWI1_ENABLED
#define TWI_INSTANCE_ID     1
#endif



//==========================================================
// <e> GPIOTE_ENABLED - nrf_drv_gpiote - GPIOTE peripheral driver - legacy layer
//==========================================================
#ifndef GPIOTE_ENABLED
#define GPIOTE_ENABLED 1
#endif
// <o> GPIOTE_CONFIG_NUM_OF_LOW_POWER_EVENTS - Number of lower power input pins 
#ifndef GPIOTE_CONFIG_NUM_OF_LOW_POWER_EVENTS
#define GPIOTE_CONFIG_NUM_OF_LOW_POWER_EVENTS 4
#endif

// <o> GPIOTE_CONFIG_IRQ_PRIORITY  - Interrupt priority
 

// <i> Priorities 0,2 (nRF51) and 0,1,4,5 (nRF52) are reserved for SoftDevice
// <0=> 0 (highest) 
// <1=> 1 
// <2=> 2 
// <3=> 3 
// <4=> 4 
// <5=> 5 
// <6=> 6 
// <7=> 7 

#ifndef GPIOTE_CONFIG_IRQ_PRIORITY
#define GPIOTE_CONFIG_IRQ_PRIORITY 6
#endif

// </e>

// <e> NRFX_CLOCK_ENABLED - nrfx_clock - CLOCK peripheral driver
//==========================================================
#ifndef NRFX_CLOCK_ENABLED
#define NRFX_CLOCK_ENABLED 1
#endif
// <o> NRFX_CLOCK_CONFIG_LF_SRC  - LF Clock Source
 
// <0=> RC 
// <1=> XTAL 
// <2=> Synth 
// <131073=> External Low Swing 
// <196609=> External Full Swing 

#ifndef NRFX_CLOCK_CONFIG_LF_SRC
#define NRFX_CLOCK_CONFIG_LF_SRC 1
#endif

// <o> NRFX_CLOCK_CONFIG_IRQ_PRIORITY  - Interrupt priority
 
// <0=> 0 (highest) 
// <1=> 1 
// <2=> 2 
// <3=> 3 
// <4=> 4 
// <5=> 5 
// <6=> 6 
// <7=> 7
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

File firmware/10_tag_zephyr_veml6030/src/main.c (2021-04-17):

#include <zephyr.h>
#include <device.h>
#include <devicetree.h>
#include <logging/log.h>
#include <drivers/sensor.h>

LOG_MODULE_REGISTER(main, LOG_LEVEL_INF);

static const struct device *get_veml6030_device(void)
{
	//const struct device *dev = DEVICE_DT_GET_ANY(bosch_bme280);
	const struct device *dev = device_get_binding("VEML6030");

	if (dev == NULL) {
		/* No such node, or the node does not have status "okay". */
		printk("\nError: no device found.\n");
		return NULL;
	}

	if (!device_is_ready(dev)) {
		printk("\nError: Device \"%s\" is not ready; "
		       "check the driver initialization logs for errors.\n",
		       dev->name);
		return NULL;
	}

	printk("Found device \"%s\", getting sensor data\n", dev->name);
	return dev;
}

void read_device(const struct device *dev)
{
	struct sensor_value val;
	uint32_t lum = 0U;
	if (sensor_sample_fetch_chan(dev, SENSOR_CHAN_LIGHT) != 0) {
		LOG_ERR("sensor: sample fetch fail.\n");
		return;
	}

	if (sensor_channel_get(dev, SENSOR_CHAN_LIGHT, &val) != 0) {
		LOG_ERR("sensor: channel get fail.\n");
		return;
	}

	lum = val.val1;
	LOG_INF("sensor: lum reading: %d\n", lum);

}

void main(void)
{
	LOG_INF("Hello from Sensor Tag I2C env");


	LOG_INF("VEML6030 light sensor application\n");

	const struct device *dev = get_veml6030_device();
	if (!dev) {
		LOG_ERR("sensor: device not found.\n");
		return;
	}

	while (1) {
		read_device(dev);
		LOG_INF("loop");
		k_sleep(K_MSEC(4000));
	}
}

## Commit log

2021-02-07 First implementation and size check
    [BA2032SM.stl, BA2032SM.stp, BME280.step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]
2021-02-07 Moved components and routed the board
    [nrf52-sensor-tag.kicad_pcb, nrf52-sensor-tag.sch]
2021-02-07 Attached the sensors VCC to GPIOs of the nrf instead vcc (incl. a jumper just in case)
    [nrf52-sensor-tag.kicad_pcb, nrf52-sensor-tag.sch]
2021-02-07 Add debug connector
    [nrf52-sensor-tag.kicad_pcb, nrf52-sensor-tag.sch]
2021-02-08 Beautify schematics + added debug connector
    [nrf52-sensor-tag.kicad_pcb, nrf52-sensor-tag.sch]
2021-02-08 Finalized layout
    [nrf52-sensor-tag.kicad_pcb, nrf52-sensor-tag.sch]
2021-02-08 Fix button orientation
    [nrf52-sensor-tag.kicad_pcb]
2021-02-09 Add new alternative sensors
    [MS860702BA01-50.stp, VEML6030.stl, VEML6030.stp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]
2021-02-09 Add MS88SF2 nRF52 Module and re-arranged components
    [nrf52-sensor-tag.kicad_pcb, nrf52-sensor-tag.sch]
2021-02-10 Add 3D Model for MS88SF1
    [nrf52-sensor-tag.kicad_pcb]
2021-02-10 Add Gerbers and BOM to manufacturing folder
    [ThreadSensorTag_BOM.xlsx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]
2021-02-13 successfully running Thread to MQTT
2021-02-14 Removed unneseccary components because the battery is a very undisturbed source
    [nrf52-sensor-tag.kicad_pcb, nrf52-sensor-tag.sch]
2021-02-16 leds running with dongle dts
2021-03-15 failing device get null
    [main.c]
2021-03-15 sensor device not found
2021-03-17 first twi integration for max44009 sensor
2021-03-26 added discord and ongoing sensor
2021-04-04 Add RGB LED
    [nrf52-sensor-tag.kicad_pcb, nrf52-sensor-tag.sch]
2021-04-04 Fix DRC errors
    [nrf52-sensor-tag.kicad_pcb]
2021-04-04 Add Gerber files plot
    [nrf52-sensor-tag-B_Cu.gbr, nrf52-sensor-tag-B_Mask.gbr, nrf52-sensor-tag-B_SilkS.gbr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]
2021-04-10 initial print log
2021-04-11 first board and dts version
2021-04-11 corrected dts error and pushed boards on top
    [main.c]
2021-04-12 running user button callback
2021-04-12 building Thread
2021-04-12 samples plan
2021-04-13 thread log
2021-04-15 thread config and mqttsn
2021-04-15 #4 Sensor Tag improvements suggestions
    https://github.com/HomeSmartMesh/nrf52_thread_sensortag/issues/4
    [APHF1608.STEP, nrf52-sensor-tag.kicad_pcb, nrf52-sensor-tag.sch]
2021-04-15 Generated BOM and Gerbers for v1.1
    [ThreadSensorTag_BOM.xlsx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]
2021-04-15 Add i2c example (failed for 0x40 and 0x76)
    [main.c]
2021-04-16 preparing for i2c
2021-04-17 pinging all i2c sensors
2021-04-17 updating for veml light sensor
2021-04-17 log vishay no sensor
2021-04-17 finding device fetch fails
    [main.c, veml6030.c]
2021-06-07 New edge cut + sensor turned by 68°
    [nrf52-sensor-tag.kicad_pcb]
2021-06-07 Generated html BOM
2021-06-07 Generated Gerber files
    [nrf52-sensor-tag-B_Cu.gbr, nrf52-sensor-tag-B_Mask.gbr, nrf52-sensor-tag-B_SilkS.gbr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]
2021-08-25 Added Open Source Hardware Logo + Made in Germany + Designed with KiCad
    [nrf52-sensor-tag.kicad_pcb]
2021-08-28 Add new battery holder component
    [BAT-HLD-001.stp]
2021-08-28 Rerouting using new Battery Holder (autorouted)
    [APHF1608.IGS, APHF1608SEEQBDZGKC_KNB.step, APHF1608_.STEP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]
2021-08-29 Finalized schematics + generated manufacturing files
    [3d-file.step, ThreadSensorTag_BOM.xlsx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]
2021-09-02 Add 100uF cap + regenerated gerbers incl. F+B_Paste
    [nrf52-sensor-tag-B_Cu.gbr, nrf52-sensor-tag-B_Mask.gbr, nrf52-sensor-tag-B_Paste.gbr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]
2022-09-13 Replaced light sensor VEML6030 with LTR-308ALS-01
    [nrf52-sensor-tag.kicad_pcb, nrf52-sensor-tag.kicad_sch]
2023-09-02 Port from KiCad 5 to KiCad 6
    [nrf52-sensor-tag.kicad_pcb, nrf52-sensor-tag.kicad_sch]
2023-09-02 Try to fix KiCad Version issue
    [nrf52-sensor-tag.kicad_pcb, nrf52-sensor-tag.kicad_sch]
2023-09-03 Removed old kicad file
    [nrf52-sensor-tag.sch]
2023-09-03 Fix DRC violations with KiCad 7
    [nrf52-sensor-tag.kicad_pcb]
2023-09-03 Change KiBot action pcb_print to pcbdraw
2024-05-08 Add enclosure STL files
    [trIoT_oberteil_PT2-1mm.stl, trIoT_unterteil_PT2-1mm.stl]
